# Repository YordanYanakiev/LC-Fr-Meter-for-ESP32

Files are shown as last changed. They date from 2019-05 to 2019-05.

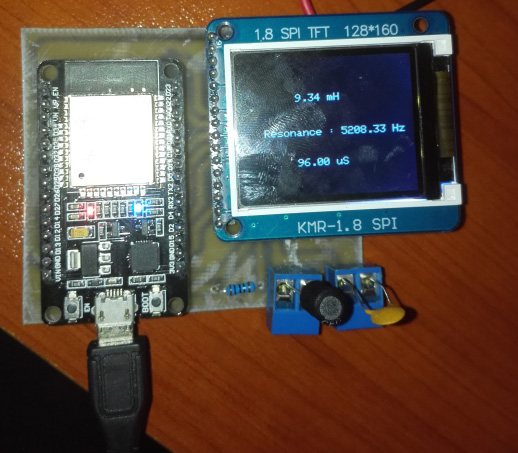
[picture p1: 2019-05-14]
LCFrV1.jpg

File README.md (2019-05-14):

# LC-Fr-Meter-for-ESP32
V1 of LC+Resonance Frequency Meter for ESP32

 I've searched for a while for ESP32 based LC ( Induction / Capacitance ) meter but seems like everyone were arduino based.
So.. I've created one which actually looks better than the rest ;)
It's based on LM393N but You could replace it with similar.
In the github - you can get the full EAGLE PCB single layer optimized board and the circuit with a few libraries which I've created as well, and the demo project.
ENJOY ! :) ...

*** NOTE that as better the quality and smaller is the tolerance of the capacitor - the better readings you will get.
*** It is used 10 nF 10% capacitor. If You have other one, or you need to measure higher or lower inductances - change the capacitor, and reflect it's changes inside the code.

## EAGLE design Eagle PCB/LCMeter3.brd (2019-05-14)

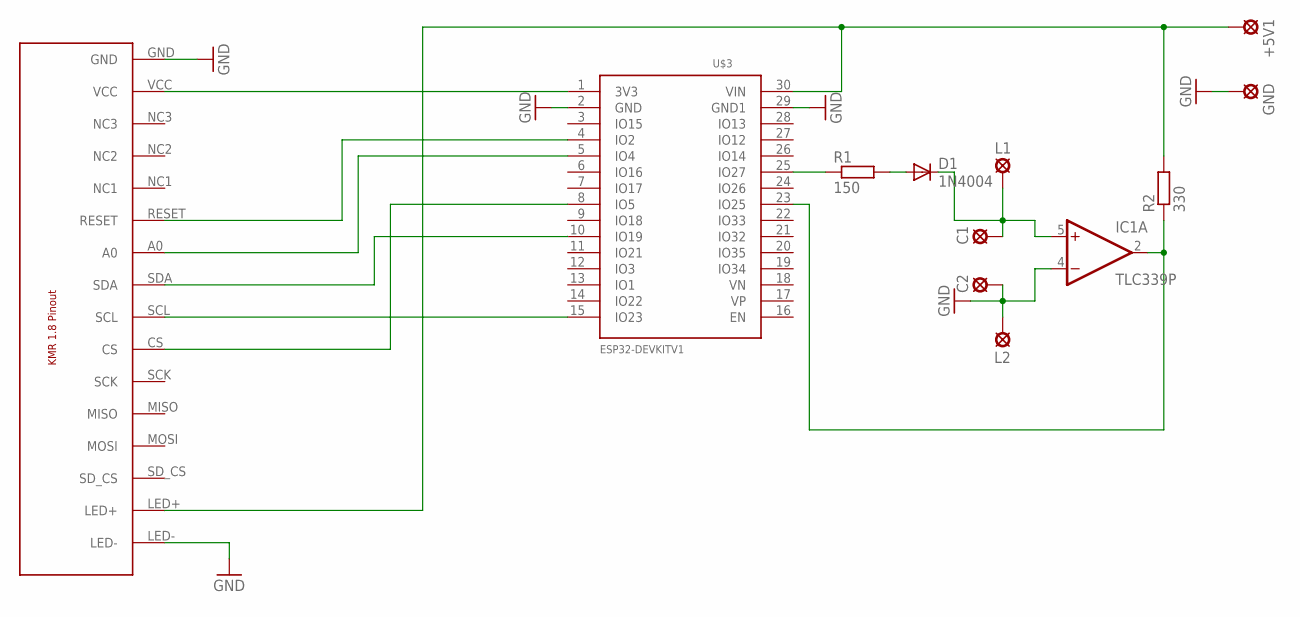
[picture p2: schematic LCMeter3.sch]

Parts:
+5V1: LSP10
C1, C2: LSP10
D1: 1N4004; DO41-10
GND: LSP10
IC1: TLC339P; DIL14
L1, L2: LSP10
R1: 150; 0207/10
R2: 330; 0207/10
U$3: ESP32DEVKITV1; ESP32-DEVKITV1
U$4: KMR-1.8

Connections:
GND: C2.MP, GND.MP, IC1.4 (-IN), IC1.12 (GND), L2.MP, U$3.2 (GND), U$3.29 (GND1), U$4.GND, U$4.LED-
unnamed: D1.A, R1.2
unnamed: C1.MP, D1.C, IC1.5 (+IN), L1.MP
unnamed: R1.1, U$3.25 (IO27)
unnamed: IC1.2 (OUT), R2.1, U$3.23 (IO25)
unnamed: U$3.1 (3V3), U$4.VCC
unnamed: U$3.15 (IO23), U$4.SCL
unnamed: U$3.10 (IO19), U$4.SDA
unnamed: U$3.8 (IO5), U$4.CS
unnamed: U$3.5 (IO4), U$4.A0
unnamed: U$3.4 (IO2), U$4.RESET
V+: +5V1.MP, IC1.3 (V+), R2.2, U$3.30 (VIN), U$4.LED+

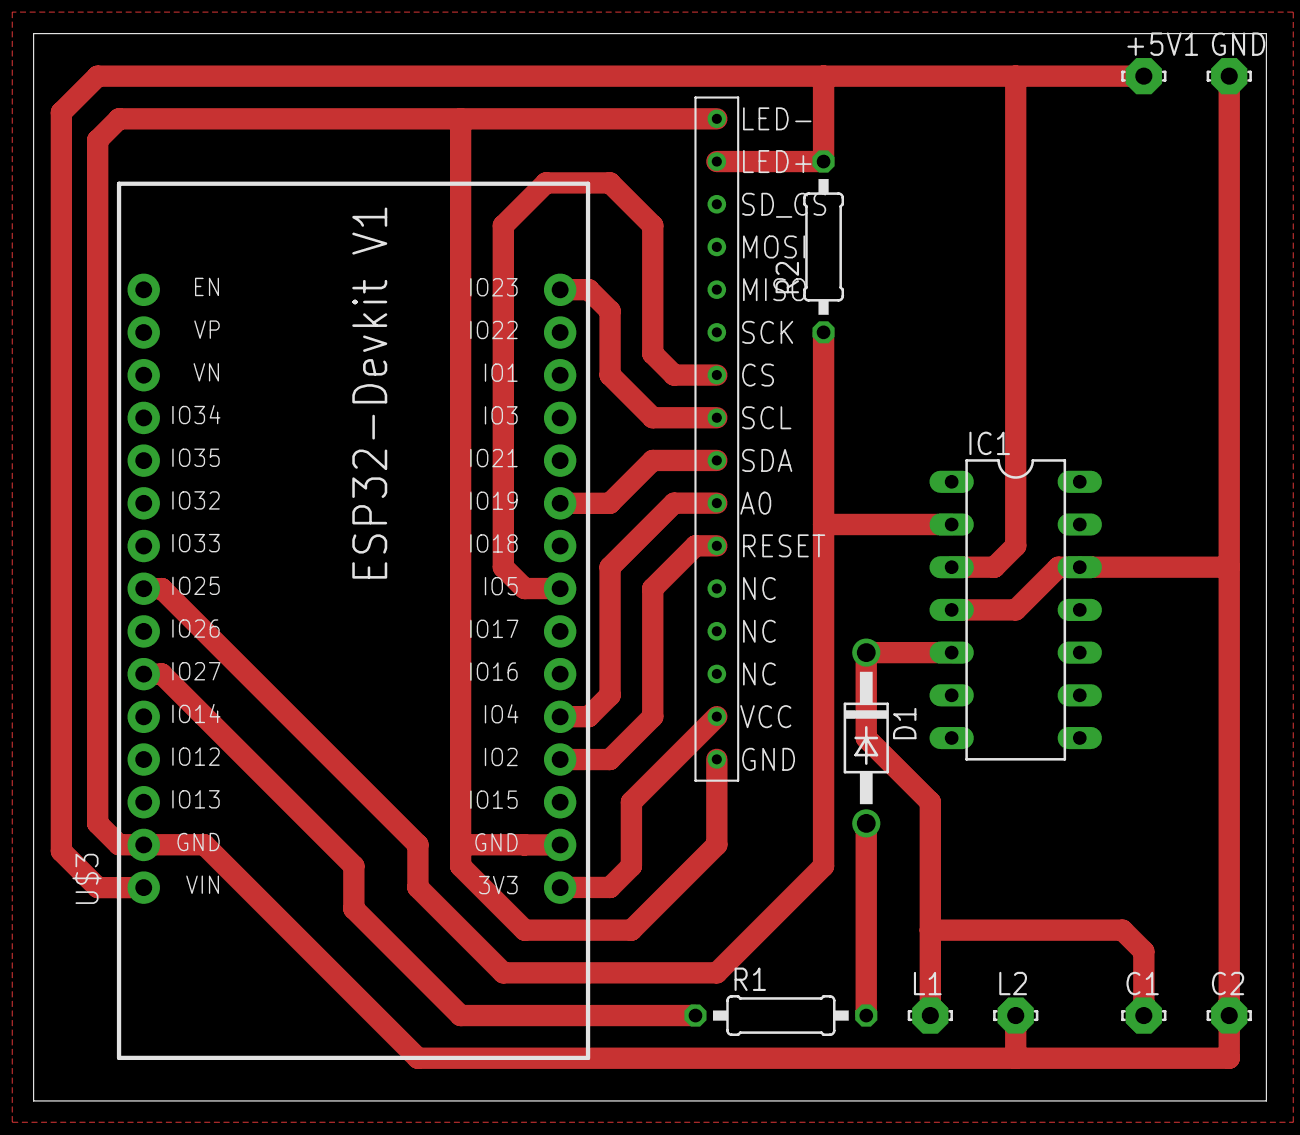
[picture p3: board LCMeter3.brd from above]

Board: 2 copper layers, 73.3 x 63.5 mm, 12 parts (0 on the bottom side), 12 nets.

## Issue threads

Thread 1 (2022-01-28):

Can't find pins for my IPS screen

mathewriver, 2022-01-28:
There's not pinout for the TJCTM24024-SPI lcd screen in the project. What's the wiring for this screen?

YordanYanakiev, 2022-01-28:
this is not the one which I were using.

YordanYanakiev, 2022-01-28:
mine is KMR 1.8 SPI. You have to adapt yours.

mathewriver, 2022-01-28:
I know yours is different, that's why I'm asking. Do you know how I can change that?

YordanYanakiev, 2022-01-28:
Never had like Yours to play with it to be honest. :|

mathewriver, 2022-01-28:
Can you get any idea from this wiring?

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

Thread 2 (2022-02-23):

Concerns about your hardware + enhancements with a comparator instead of an OPAMP

trafokopf, 2022-02-23:
Hi,

I have a few concerns about your hardware setup. These do not mean it is crap or not working at all, it is just about some issues I see.

1) The pullup resistor on the output of an LM358 is useless, as it has a full-blown output stage. It is able to supply both GND and VCC.
2) The pullup resistor is quite small. With 5V and such a small resistor the 3V3 GPIO could be damaged. Something between 10k and 47k is better (if PullUp needed)
3) I dont know about the LM358, but the LT1013 (pin compatible+improved LM358) works with 3V3. This would make operation much safer for GPIOs.
4) The LM393 is a much higher speed comparator. MHzs out of this device is not a problem. A comparator would do the job much better and would allow for measurements, I think, down to 10ths of nano-Henrys. Measuring a 1µH inductor with a 10nF capacitor and a LM358/LT1013 is impossible. It will output some high-ripple DC around 3V with your hardware setup, I assume.
5) Schematics in PNG would be a pleasure for all others interested in this project.

Anyway, thanks for showing me with your project how easy inductors could be measured. Thank you very much for your effort and sharing with us!

YordanYanakiev, 2022-02-23:
Ha ! Nice teardown!
For sure these is quite good notes, and for sure i will learn from them. :)
I am happy that the project is useful.
Unfortunately I am not able to work on a side projects ( like that one ) since the real work kicking hard right now, but I would love to hear if you make it better, and if you share a circuit probably we will make more peoples happy :)
(which is the point I believe )

trafokopf, 2022-02-23:
About that point of sharing my stuff:
My LC-Meter isn't finished yet, until now it is just a (different than yours) ESP32 Board + a display in a case. The inductor-stuff isn't built yet, for the same reason (real work to do...). I am working the last days after work on a easy-to-use-wifi-manager, display and other stuff, as well as adapting your inductor code and testing it function by function.
I am pretty sure it will work out of the box when I connect the hardware (sooner or later).
So, for the software-part I have nothing of use to you. Different board, no enhancements to your code so far.

For the hardware part this I can share right now:
(I will built my circuit this way)

I have thrown together a LTSpice simulation that shows how the LM393 performs with a 100n cap and a 1uH inductor.
Attached screenshot and simulation file.
Addition to point 4) from first post: The LM393 needs a pullup on output. 10k recommended.

The diode is a 1N4148, much smaller than 400x. In screenshot you see the small current needed (I(D1)).
You see also after the charge pulse it needs a few microseconds to stabilize. I don't know about the timing of the code, but maybe the should be a few µS before pulseIn.

The circuit could be powered by a current limited and isolated DC/DC and resistors and opto couplers for a LC meter that does not care about high voltage charged capacitors. it just does not measure anything while the high voltage (very slow) gets discharged and no signal could be measured due to overdrive.

output of the 1uh/100nf combination is 465khz, which is much more accurate to measure rather than >1mhz. the error of a few us is less relevant in a longer period of time. Also my multimeter is more accurate with a 100nF capacitor (the one I have chosen is 100.1nF on my multimeter).
You could play around with values in simulation and see even >1MHz signals produce a rock stable 0/3V rectangle output.

This combination will care about 10..50nHs also. Which is the range of a few cm wire/track easily. The measuring procedure will be:
Give charge pulses + display the result in a loop.
Short the probes.
Read example 30nH.
Put in inductor.
Substract 30nH from result.

Of course this could be implemented in software. Just to show the way to minimize error.

[espmeter-lm393.asc.zip](https://github.com/YordanYanakiev/LC-Fr-Meter-for-ESP32/files/8126981/espmeter-lm393.asc.z
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
ip)

trafokopf, 2022-02-23:
something wrong with the zip. here again.
[espmeter-lm393.asc.zip](https://github.com/YordanYanakiev/LC-Fr-Meter-for-ESP32/files/8127109/espmeter-lm393.asc.zip)

trafokopf, 2022-02-23:
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

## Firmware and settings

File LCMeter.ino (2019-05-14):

#include "arduino.h"
#include <Adafruit_GFX.h>
#include <Adafruit_ST7735.h>
#include <SPI.h>

#define serial

#define TFT_CS     5
#define TFT_RST    2 
#define TFT_DC     4

#define TFT_SCLK   23
#define TFT_MOSI   19

#define charge_PIN GPIO_NUM_27
#define freqIn_PIN GPIO_NUM_25


Adafruit_ST7735 * tft;


double pulse, frequency, capacitance, inductance;
unsigned long pl;

portMUX_TYPE myMutex = portMUX_INITIALIZER_UNLOCKED;

void setup()
{

	Serial.begin( 115200 );
	pinMode( freqIn_PIN, INPUT );
	pinMode( charge_PIN, OUTPUT );
	

	tft = new Adafruit_ST7735( TFT_CS, TFT_DC, TFT_MOSI, TFT_SCLK, TFT_RST );
	tft->initR( INITR_BLACKTAB );//initialize a ST7735S chip, black tab  
	tft->setRotation( 1 );
	tft->fillScreen( ST7735_BLACK );
	
	delay( 300 );
}

void loop()
{
	taskENTER_CRITICAL( &myMutex );
		digitalWrite( charge_PIN, HIGH );
		delay( 5 );//give some time to charge inductor.
		digitalWrite( charge_PIN, LOW );
		delayMicroseconds( 100 ); //make sure resination is measured
	
		pulse = pulseIn( freqIn_PIN, HIGH, 5000 );//returns 0 if timeout
	taskEXIT_CRITICAL( &myMutex );
	//pl = pulseIn( freqIn, HIGH, 5000 );//returns 0 if timeout

	//Serial.println( pulse );
	if( pulse > 0.1 )
	{ //if a timeout did not occur and it took a reading:
		capacitance = 1.E-8; //10 nf
		frequency = 1.E6 / ( 2 * pulse );
		inductance = 1. / ( capacitance * frequency * frequency * 4. * 3.14159 * 3.14159 );//one of my profs told me just do squares like this
		inductance *= 1E6; //note that this is the same as saying inductance = inductance*1E6
		
		if( inductance >= 1000 )
		{
			drawTexxt( 50, 94, 100, String( pulse ) + " uS" );

			drawTexxt( 50, 34, 100, String( inductance / 1000 ) + " mH" );
			drawTexxt( 20, 66, 120, "Resonance : " + String( frequency ) + " Hz" );
			/*
			Serial.print( "High for uS:" );
			Serial.print( pulse );
			Serial.print( "\tfrequency Hz:" );
			Serial.print( frequency );
			Serial.print( "\tinductance mH:" );
			Serial.println( inductance / 1000 );
			*/
			delay( 300 );
		
		}
		else
		{

			drawTexxt( 50, 94, 100, String( pulse ) + " uS" );

			drawTexxt( 50, 34, 100, String( inductance ) + " uH" );
			drawTexxt( 20, 66, 120, "Resonance : " + String( frequency ) + " Hz" );
			/*
			Serial.print( "High for uS:" );
			Serial.print( pulse );
			Serial.print( "\tfrequency Hz:" );
			Serial.print( frequency );
			Serial.print( "\tinductance uH:" ); Serial.println( inductance );
			*/

			delay( 300 );
		
		}
	}
	else 
		if( pulse < 0.1 )
		{
			drawTexxt( 50, 94, 100, "" );
			drawTexxt( 50, 34, 100, "Insert Inductor" );
			drawTexxt( 20, 66, 120, "" );

			delay( 500 );
			
		}

}


void drawTexxt( int16_t x, int16_t y, int16_t maxTextWidth, String text )
{
	tft->fillRect( x, y, maxTextWidth, 20, ST7735_BLACK );
	tft->setCursor( x, y );
	tft->setTextColor( ST7735_WHITE );
	tft->setTextWrap( false );
	tft->print( text );
}
